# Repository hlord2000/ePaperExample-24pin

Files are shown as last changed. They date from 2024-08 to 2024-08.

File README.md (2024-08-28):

# A KiCAD 8 Schematic for Waveshare/Good Display 24-pin ePaper Displays

<p align="center">
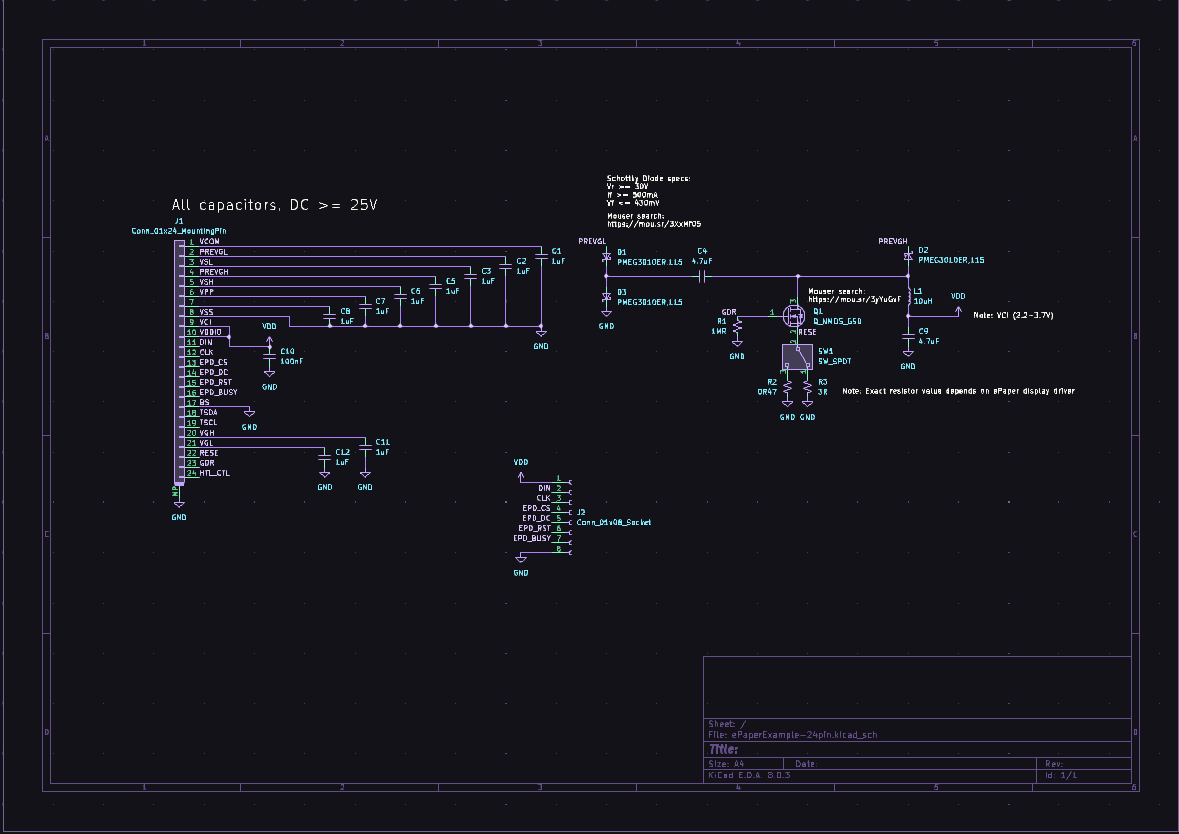
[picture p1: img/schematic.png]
Schematic
  
</p>

Based on the Waveshare ePaper shield. Includes links to parametric search for critical components.  

<p align="center">
  Board
</p>

**Please refer to the datasheet for your specific driver IC to confirm component values and specifications.**

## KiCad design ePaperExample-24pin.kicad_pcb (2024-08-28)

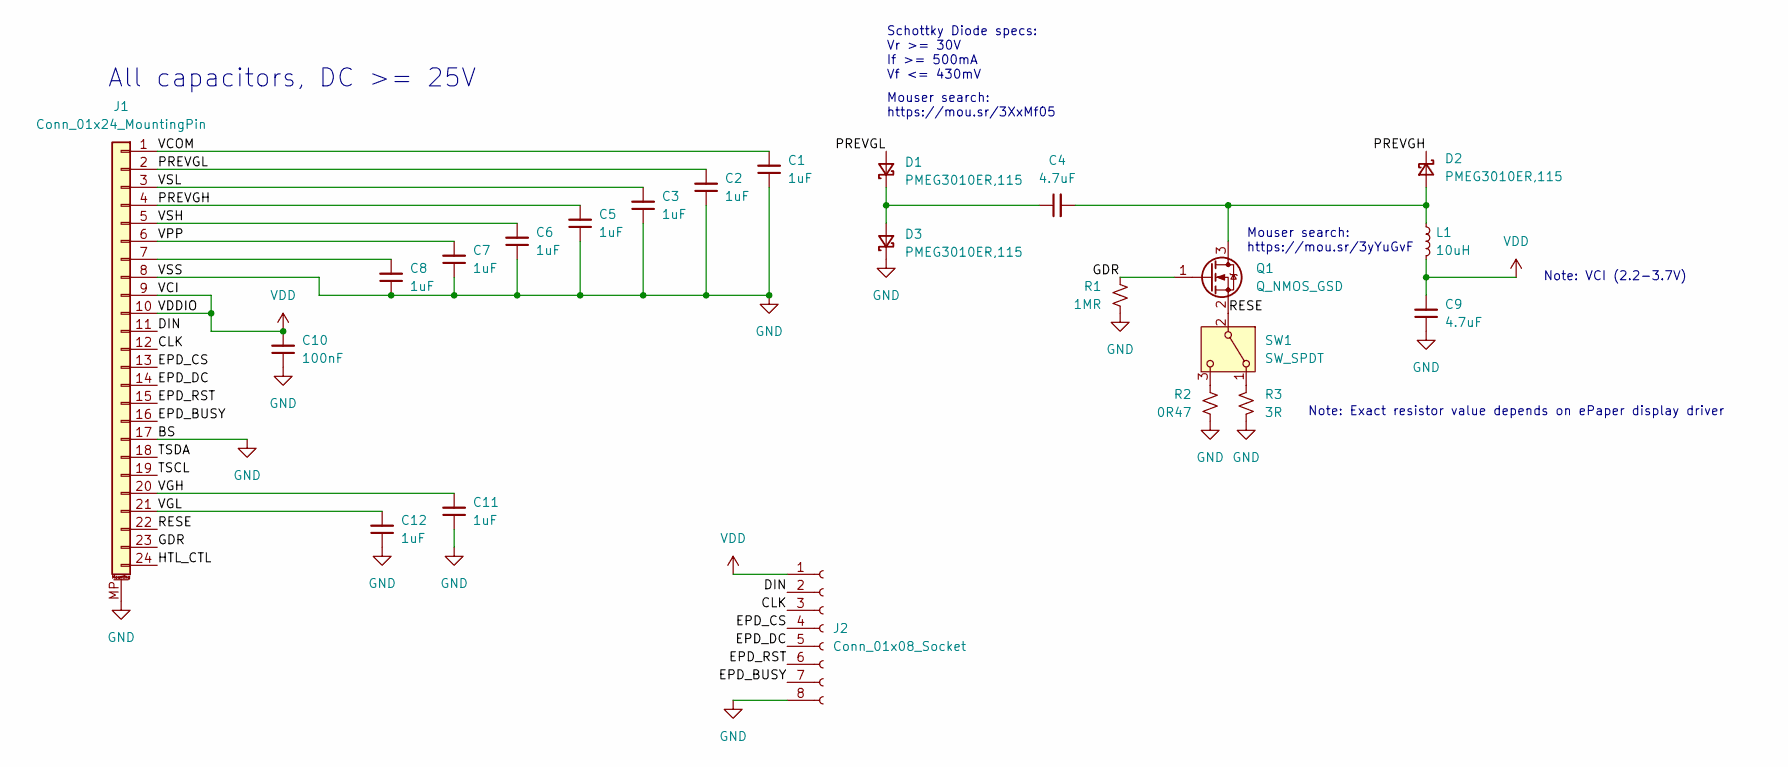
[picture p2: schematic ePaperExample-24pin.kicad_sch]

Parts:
C1, C2, C3, C5, C6, C7, C8, C11, C12: 1uF; C_0402_1005Metric; LCSC C52923
C4, C9: 4.7uF; C_0402_1005Metric; LCSC C2858031
C10: 100nF; C_0402_1005Metric; LCSC C307331
D1, D2, D3: PMEG3010ER,115; D_SOD-123; LCSC C456106
J1: Conn_01x24_MountingPin; TE_2-1734839-4_1x24-1MP_P0.5mm_Horizontal; LCSC C2911766
J2: Conn_01x08_Socket; PinHeader_1x08_P2.54mm_Vertical
L1: 10uH; L_0805_2012Metric; LCSC C2909263
Q1: Q_NMOS_GSD; SOT-23; LCSC C414015
R1: 1MR; R_0402_1005Metric; LCSC C26083
R2: 0R47; R_0603_1608Metric; LCSC C186564
R3: 3R; R_0603_1608Metric; LCSC C23157
SW1: SW_SPDT; SW_SPDT_PCM12; LCSC C109335

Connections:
/CLK: J1.12, J2.3
/DIN: J1.11, J2.2
/EPD_BUSY: J1.16, J2.7
/EPD_CS: J1.13, J2.4
/EPD_DC: J1.14, J2.5
/EPD_RST: J1.15, J2.6
/GDR: J1.23, Q1.1 (G), R1.1
/HTL_CTL: J1.24
/PREVGH: C5.2, D2.1 (K), J1.4
/PREVGL: C2.2, D1.2 (A), J1.2
/RESE: J1.22, Q1.2 (S), SW1.2 (B)
/TSCL: J1.19
/TSDA: J1.18
/VCOM: C1.2, J1.1
/VGH: C11.2, J1.20
/VGL: C12.2, J1.21
/VPP: C7.2, J1.6
/VSH: C6.2, J1.5
/VSL: C3.2, J1.3
GND: C1.1, C2.1, C3.1, C5.1, C6.1, C7.1, C8.1, C9.1, C10.1, C11.1, C12.1, D3.1 (K), J1.8, J1.17, J1.MP (MountPin), J2.8, R1.2, R2.2, R3.2
unnamed: C4.1, D1.1 (K), D3.2 (A)
unnamed: C4.2, D2.2 (A), L1.1, Q1.3 (D)
unnamed: C8.2, J1.7
unnamed: R3.1, SW1.1 (A)
unnamed: R2.1, SW1.3 (C)
VDD: C9.2, C10.2, J1.9, J1.10, J2.1, L1.2

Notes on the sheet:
Note: Exact resistor value depends on ePaper display driver
Note: VCI (2.2-3.7V)
Mouser search: https://mou.sr/3XxMf05
All capacitors, DC >= 25V
Mouser search: https://mou.sr/3yYuGvF
Schottky Diode specs: Vr >= 30V If >= 500mA Vf <= 430mV

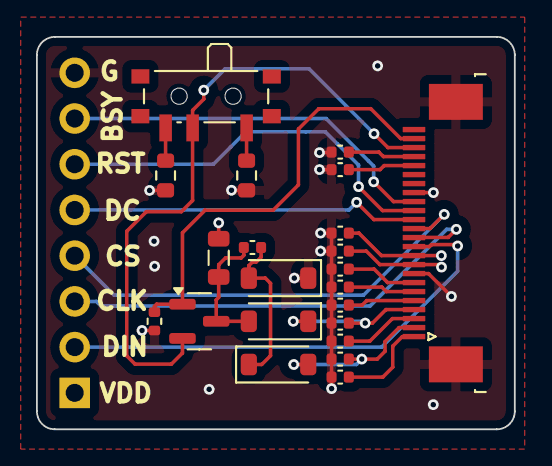
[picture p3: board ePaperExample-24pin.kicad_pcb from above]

Board: 4 copper layers, 26.5 x 21.8 mm, 23 parts (1 on the bottom side), 23 nets.

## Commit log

2024-06-17 Initial commit.
    [ePaperExample-24pin.kicad_pcb, ePaperExample-24pin.kicad_sch]
2024-08-28 Updated to reflect tested board
    [ePaperExample-24pin.kicad_sch]
2024-08-28 Added updated schematic, added PCB layout
    [ePaperExample-24pin.kicad_pcb, ePaperExample-24pin.kicad_sch]
